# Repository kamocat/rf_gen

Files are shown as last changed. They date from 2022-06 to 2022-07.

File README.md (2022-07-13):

# RF Generator
500W RF generator, tuned for 13.56MHz
Based on the paper [1kW Wideband Class E Power Amplifier](https://superlab.stanford.edu/publication/kw_mhz_wideband_class_e_power_amplifier_jiale/) from the Stanford Superlab.

I removed the duplicate circuit (for simplicity), added a FET driver, clock, and Arduino for control.

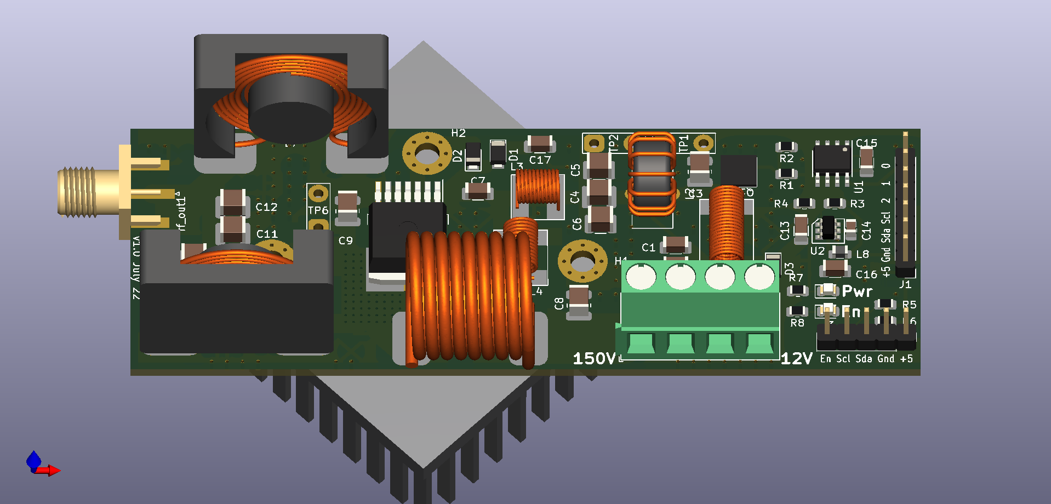
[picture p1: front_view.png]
Front view of PCBA Front View


## Cost breakdown
| Category | Price | Description |
| --- | --- | --- |
| Assemblies | 19.95 | Arduino & Si5351 |
| Components | 47.25 | Parts that get soldered on |
| Consumables | 33.94 | Solder and magnet wire |
| Hardware | 4.89 | Screws, heatsink, thermal interface pad |
| PCB | 30.00 | From OSH Park. 2 oz copper |

## Electrical simulation
Simulation is done with LTSpice.
You will need the spice models for the [SiC mosfet](https://www.genesicsemi.com/sic-mosfet/G3R30MT12J/G3R30MT12J_SPICE.zip) and the [GaN mosfet](https://gansystems.com/wp-content/uploads/2020/02/GS61004B-Spice-Models-V4P2.zip)

## Thermal simulation
Simulation is done with Elmer / FreeCAD. Work in progress...

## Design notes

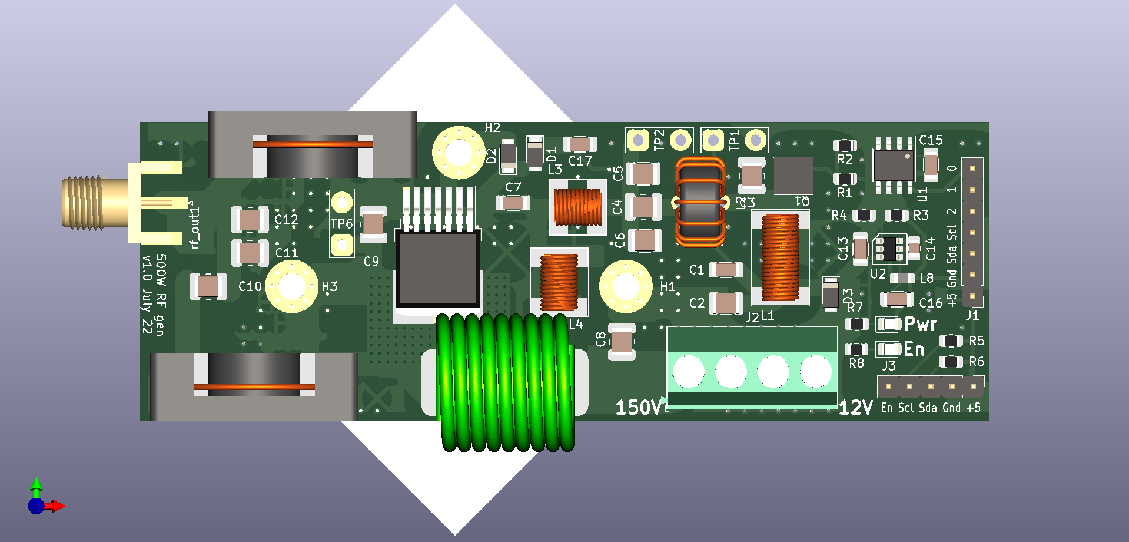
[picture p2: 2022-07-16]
top_view.png

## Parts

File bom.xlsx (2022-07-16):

Designator | Package | Quantity | Designation | Supplier and ref | Price | Extended | Category | Notes
R2,R1 | R_0805_2012Metric | 2 | 1 | 667-ERJ-6GEYJ1R0V | 0.054 | 0.108 | Component
R8,R7 | R_0805_2012Metric | 2 | 330 | 652-CR0805FX-3740ELF | 0.029 | 0.058 | Component
C14 | C_0805_2012Metric | 1 | 100n | 187-CL21B104KACNNNC | 0.028 | 0.028 | Component
C7,C1,C17 | C_1206_3216Metric | 3 | 100n | 81-GRM3195C1H104JA5D | 0.374 | 1.122 | Component
R6,R4,R5 | R_0805_2012Metric | 3 | 10k | 603-RT0805FRE0710KL | 0.08 | 0.24 | Component
C16,C13,C15 | C_1206_3216Metric | 3 | 10u | 187-CL31B106MOHNNNE | 0.09 | 0.27 | Component
L4 | 2222SQ-111 | 1 | 110n | 994-2222SQ-111JEC (https://www.mouser.com/ProductDetail/81-GRM3195C1H104JA5D) | 1.89 | 1.89 | Component
C9,C10 | C_1111_2828Metric | 2 | 180p | https://www.mouser.com/ProductDetail/Vishay-Vitramon/VJ1111D181KXGAJ?qs=FkXh%252BYPvS2puVPl%2FhgCUnw%3D%3D | 1.09 | 2.18 | Component
C6,C2 | C_1210_3225Metric | 2 | 1n | 581-12105U102JAT2A | 0.68 | 1.36 | Component
L1 | 2222SQ-221 | 1 | 220n | 994-2222SQ-221JEC (https://www.mouser.com/ProductDetail/621-DFLS230-7) | 1.85 | 1.85 | Component
C5,C3 | C_1111_2828Metric | 2 | 220p | 77-VJ1111D221JXLAJ (https://www.mouser.com/ProductDetail/710-150080GS75000) | 1.13 | 2.26 | Component
C8,C4,C11 | C_1111_2828Metric | 3 | 270p | 77-VJ1111D271JXLAJ (https://www.mouser.com/ProductDetail/485-2045) | 1.31 | 3.93 | Component
L8 | L_0805_2012Metric | 1 | 3.3u | 810-MLZ2012M3R3HT000 (https://www.mouser.com/ProductDetail/782-ABX00028) | 0.17 | 0.17 | Component
L7,L2 | 2929SQ-501 | 2 | 500n | https://www.mouser.com/ProductDetail/Coilcraft/2929SQ-501JEC?qs=zCSbvcPd3pbfVuBnETc4Rw%3D%3D | 2.07 | 4.14 | Component
R3 | R_0805_2012Metric | 1 | 52.3k | 603-RT0805FRE0752K3L (https://www.mouser.com/ProductDetail/994-2222SQ-90NJEC) | 0.081 | 0.081 | Component
L6 | inductor_air_15x15 | 1 | 760n | N/A | 0 | 0 | Component | Hand-wind, plastic 15mm core
L5 | inductor_air_15x15 | 1 | 880n | N/A | 0 | 0 | Component | Hand-wind, plastic 15mm core
L3 | 2222SQ-90N | 1 | 90n | 994-2222SQ-90NJEC | 1.85 | 1.85 | Component
U2 | TSOT26 | 1 | AP62150 | 621-AP62150WU-7 | 0.44 | 0.44 | Component
J3 | PinHeader_1x05_P2.54mm_Vertical | 1 | Conn_01x05_Male | 782-ABX00028 | 12 | 12 | Component
J1 | PinHeader_1x07_P2.54mm_Vertical | 1 | Conn_01x07_Male | 485-2045 (https://www.mouser.com/ProductDetail/905-G3R350MT12J) | 7.95 | 7.95 | Component
rf_out1 | SMA_EdgeMount | 1 | Conn_Coaxial | 712-CONSMA020.062-G (https://www.mouser.com/ProductDetail/667-ERJ-6GEYJ1R0V) | 3.93 | 3.93 | Component
D2,D3,D1 | D_PowerDI-123 | 3 | DFLS230 | 621-DFLS230-7 (https://www.mouser.com/ProductDetail/603-RT0805FRE0752K3L) | 0.7 | 2.1 | Component
Q2 | TO-263-7_heatsink | 1 | G3R350MT12J | 905-G3R350MT12J (https://www.mouser.com/ProductDetail/603-RT0805FRE0710KL) | 6.06 | 6.06 | Component
Q1 | GaNpx | 1 | GS61004B | 499-GS61004B-MR | 7.22 | 7.22 | Component
D4,D5 | LED_0805_2012Metric | 2 | LED | 710-150080GS75000 (https://www.mouser.com/ProductDetail/712-CONSMA020.062-G) | 0.019 | 0.038 | Component
H3,H1,H2 | MountingHole_3.2mm_M3_Pad_Via | 3 | MountingHole_Pad | 728-062809-008 | 0.05 | 0.15 | Hardware
U1 | SOIC-8_3.9x4.9mm_P1.27mm | 1 | NPC81074 | 863-NCP81074ADR2G | 1.63 | 1.63 | Component
J2 | TerminalBlock_Phoenix_MKDS-1,5-4-5.08_1x04_P5.08mm_Horizontal | 1 | Screw_Terminal_01x04 | 649-220316-H041B01LF | 0.89 | 0.89 | Component
TP6,TP1,TP2 | TestPoint_2Pads_Pitch5.08mm_Drill1.3mm | 3 | test | N/A | 0 | 0 | Component | For oscope probe
 | #16 Magnet Wire | 1 |  | Amazon (https://docs.oshpark.com/services/two-layer-hhdc/) | 11.45 | 11.45 | Consumable
 | Heat sink | 1 |  | HSB21-454515 (https://www.amazon.com/BNTECHGO-AWG-Magnet-Wire-Transformers/dp/B07H7GVR8L) | 2.11 | 2.11 | Hardware
 | PCB | 1 |  | OSH Park | 10 | 30 | PCB
 | Solder paste | 1 |  | 4902P-15G (https://www.mouser.com/ProductDetail/CUI-Devices/HSB21-454515?qs=QNEnbhJQKvZ3Ksj2ZU6gJQ%3D%3D) | 11.04 | 11.04 | Consumable
 | Thermal Interface Pad | 1 |  | 588-HS100-TP2 (https://www.mouser.com/ProductDetail/MG-Chemicals/4902P-15G?qs=YCa%2FAAYMW03JzXlgCTWNQA%3D%3D) | 2.63 | 2.63 | Hardware
 | Shipping |  |  |  |  | 7.99
 |  |  |  |  |  | 129.165

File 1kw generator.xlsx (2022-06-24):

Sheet: cost sheet
 |  |  |  |  |  |  |  |  | 14 awg = 1.6mm
Circuit | Component | PN | value | cost | qty | package | windings | length | wire diameter | resistance | power dissipated
Gate Drive
 | Sg | GS61004B (https://www.mouser.com/ProductDetail/GaN-Systems/GS61004B-MR?qs=OlC7AqGiEDkQI26Ffzps3A%3D%3D) | GAN fet | 7.22 | 1
 | Lf | 2222SQ-221_E_ (https://www.coilcraft.com/en-us/products/rf/air-core-inductors/square-air-core-inductors/1515sq-2222sq-2929sq/2222sq-221/) | 220 nH | 1.85 | 1
 | Cf |  | 220 pF | 0.06 | 1 | 0805
 | Ls | 5967000201 (https://www.mouser.com/ProductDetail/Fair-Rite/5967000201) | 650 nH | 0.85 | 1 |  | 6
 | Cs |  | 265 pF | 0.06 | 1 | 0805
 | Lm1 | 2222SQ-90N_E_ (https://www.coilcraft.com/en-us/products/rf/air-core-inductors/square-air-core-inductors/1515sq-2222sq-2929sq/2222sq-90n/) | 90 nH | 1.85 | 1
 | Cm |  | 1.5 nF | 0.01 | 1 | 0805
 | Lm2 | 2222SQ-111_E_ (https://www.coilcraft.com/en-us/products/rf/air-core-inductors/square-air-core-inductors/1515sq-2222sq-2929sq/2222sq-111/) | 110 nH | 1.85 | 1
 | Cb |  | 100 nF | 0.37 | 1 | 1206
 | D1, D2 | DFLS230 | schottky | 0.7 | 2
Power Amplifier
 | S1, S2 | G3R350MT12J (https://www.mouser.com/ProductDetail/GeneSiC-Semiconductor/G3R350MT12J?qs=zW32dvEIR3vCQ2poQ4Z4Lg%3D%3D) | SiC fet | 6.06 | 2
 | LF 1, LF 2 | 15mm air core | 880 nH |  | 2 |  | 9
 | CF 1, CF 2, CS1, CS2 | C0805C390JDGACTU (https://www.mouser.com/ProductDetail/KEMET/C0805C390JDGACTU?qs=NrXEK%2Fuukt6We1Uf8rN8WQ%3D%3D) | 39 pF | 0.26 | 4 | 1206
 | LS1, LS2 | 5967001001 (https://www.mouser.com/ProductDetail/Fair-Rite/5967001001) | 3.5 µH | 4.66 | 2 |  | 16
 | LP 1, LP 2 | 5967000301 (https://www.mouser.com/ProductDetail/Fair-Rite/5967000301) | 594 nH | 0.9 | 2 | 1206 | 6
 | CP 1, CP 2 |  | 232 pF | 0.29 | 2 | 1206
Controls
 | clock generator | Si5351 |  | 8.19
 | mcu | arduino |  | 15
 | display | OLED or 7seg |  | 2
 | knob | Encoder |  | 3

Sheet: inductor notes
Ref designator | Inductance | Resistance (mΩ) | Max current (A) | RMS current (A) | Heat loss (mW) | Core | Wire gauge | Length (mm) | Turns | OD (mm) | ID (mm) | height (mm)
L1 | 220nH | 11.0 | 2.5 | 1.6 | 17.6 | air
L2 | 650nH | 45.3 | 1.5 | 0.84 | 38.1 | mat 67 toroid | 20 | 123 | 6 | 9.5 | 4.75 | 3.3
L3 | 90nH | 5.5 | 4 | 1.75 | 9.6 | air
L4 | 110nH | 6.5 | 3.5 | 0.7 | 4.5 | air
L5 | 880nH | 49.7 | 10 | 7 | 348.1 | 15mm plastic tube | 20 | 135 | 9 | 15
L6 | 3.5uH | 99.5 | 5 | 3.5 | 348.1 | mat 67 toroid | 20 | 270 | 17.6 | 12.7 | 7.15 | 4.9
L7 | 584nH | 40.5 | 5 | 3.5 | 141.8 | mat 67 toroid | 20 | 110 | 7.2 | 12.7 | 7.15 | 4.9

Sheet: tools
K | 0.8
u0 | 1.256637061e-06 | Resources
uRod | 20 | Coil32 - Ferrite Rod Coil Calculator (https://coil32.net/online-calculators/ferrite-rod-calculator.html)
Turns | 6 | T50-2 (toroids.info)
Area (cm2) | 0.0707 | Rod Permeability Calculator - Fair Rite (fair-rite.com) (https://www.fair-rite.com/rods-calculator/)
pitch (mm) | 1.6 | https://learnemc.com/EXT/calculators/Resistance_Calculator/wire.html
length (cm) | 0.96
Inductance (uH) | 0.5330654415

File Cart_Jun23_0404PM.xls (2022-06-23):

SHOPPING CART
This is not an invoice
23-Jun-22 16:04:28
 | Mouser # | Mfr. # | Manufacturer | Customer # | Description | RoHS | Lifecycle | Order Qty. | Price (USD) | Ext.: (USD)
1 | 994-2222SQ-221JEC | 2222SQ-221JEC | Coilcraft |  | Fixed Inductors 2222 220nH Unshld 5% 5A 11mOhms | RoHS Compliant |  | 1 | $1.85 | $1.85
2 | 499-GS61004B-MR | GS61004B-MR | GaN Systems |  | MOSFET 100V, 38A, GaN E-mode, GaNPX package, Bottom-side cooled | RoHS Compliant |  | 1 | $7.22 | $7.22
3 | 994-2222SQ-90NJEC | 2222SQ-90NJEC | Coilcraft |  | Fixed Inductors 2222 90nH Unshld 5% 5A 5.5mOhms | RoHS Compliant |  | 2 | $1.85 | $3.70
4 | 905-G3R350MT12J | G3R350MT12J | GeneSiC Semiconductor |  | MOSFET 1200V 350mO TO-263-7 G3R SiC MOSFET | RoHS Compliant | New Product | 2 | $6.06 | $12.12
5 | 994-2222SQ-111JEC | 2222SQ-111JEC | Coilcraft |  | Fixed Inductors 2222 110nH Unshld 5% 5.7A 6.5mOhms | RoHS Compliant |  | 1 | $1.89 | $1.89
6 | 621-DFLS230-7 | DFLS230-7 | Diodes Incorporated |  | Schottky Diodes & Rectifiers 2.0A 30V LFF | RoHS Compliant By Exemption |  | 2 | $0.70 | $1.40
7 | 623-5967000301 | 5967000301 | Fair-Rite |  | Ferrite Toroids / Ferrite Rings 67 TOROID | RoHS Compliant |  | 2 | $0.90 | $1.80
8 | 623-5967000201 | 5967000201 | Fair-Rite |  | Ferrite Toroids / Ferrite Rings 67 TOROID 3.3mm 9.50mm | RoHS Compliant |  | 1 | $0.85 | $0.85
9 | 623-5967001001 | 5967001001 | Fair-Rite |  | Ferrite Toroids / Ferrite Rings 67 TOROID | RoHS Compliant |  | 2 | $4.66 | $9.32
10 | 81-GRM3195C1H104JA5D | GRM3195C1H104JA05D | Murata |  | Multilayer Ceramic Capacitors MLCC - SMD/SMT | RoHS Compliant |  | 10 | $0.374 | $3.74
11 | 77-VJ1111D390JXRAJ | VJ1111D390JXRAJ | Vishay |  | Multilayer Ceramic Capacitors MLCC - SMD/SMT 1111 39pF 1500V C0G 5% HI FREQ | RoHS Compliant By Exemption |  | 5 | $1.59 | $7.95
12 | 77-VJ1111D221JXLAJ | VJ1111D221JXLAJ | Vishay |  | Multilayer Ceramic Capacitors MLCC - SMD/SMT 1111 220pF 630V C0G 5% HI FREQ | RoHS Compliant By Exemption |  | 5 | $1.13 | $5.65
13 | 77-VJ1111D271JXLAJ | VJ1111D271JXLAJ | Vishay |  | Multilayer Ceramic Capacitors MLCC - SMD/SMT 1111 270pF 630V C0G 5% HI FREQ | RoHS Compliant By Exemption |  | 2 | $1.31 | $2.62
14 | 581-12105U471JAT2A | 12105U471JAT2A | Kyocera AVX |  | Multilayer Ceramic Capacitors MLCC - SMD/SMT 50V 470pF C0G 1210 5% Tol | RoHS Compliant |  | 2 | $0.77 | $1.54
15 | 581-12105U102JAT2A | 12105U102JAT2A | Kyocera AVX |  | Multilayer Ceramic Capacitors MLCC - SMD/SMT 50V 1000pF C0G 1210 5% | RoHS Compliant |  | 3 | $0.68 | $2.04
16 | 77-VJ1111D330JXLAJ | VJ1111D330JXLAJ | Vishay |  | Multilayer Ceramic Capacitors MLCC - SMD/SMT 1111 33pF 630V C0G 5% HI FREQ | RoHS Compliant By Exemption |  | 10 | $0.746 | $7.46
17 | 77-VJ1111D120GXGQJ | VJ1111D120GXGQJ | Vishay |  | Multilayer Ceramic Capacitors MLCC - SMD/SMT 1111 12pF 1000V C0G 2% HI FREQ | RoHS Compliant |  | 2 | $1.23 | $2.46
18 | 863-NCP81074ADR2G | NCP81074ADR2G | onsemi |  | Gate Drivers SINGLE CHANNEL 10A H | RoHS Compliant |  | 1 | $1.63 | $1.63
19 | 471-SMACONNECTOR | SMA CONNECTOR | LPRS |  | RF Connectors / Coaxial Connectors SMA Coaxial Straight | RoHS Compliant |  | 1 | $1.40 | $1.40
20 | 621-AP62150WU-7 | AP62150WU-7 | Diodes Incorporated |  | Switching Voltage Regulators DCDC Conv HV Buck TSOT26(STD) T&R 3K | RoHS Compliant | New Product | 1 | $0.44 | $0.44
21 | 187-CL31B106MOHNNNE | CL31B106MOHNNNE | Samsung Electro-Mechanics |  | Multilayer Ceramic Capacitors MLCC - SMD/SMT 10uF+/-20% 16V X7R 3 1206 | RoHS Compliant |  | 10 | $0.09 | $0.90
22 | 603-RT0805FRE0752K3L | RT0805FRE0752K3L | YAGEO |  | Thin Film Resistors - SMD 1/8W 52.3K ohm 1% 50ppm | RoHS Compliant By Exemption |  | 10 | $0.081 | $0.81
23 | 603-RT0805FRE0710KL | RT0805FRE0710KL | YAGEO |  | Thin Film Resistors - SMD 1/8W 10K ohm 1% 50ppm | RoHS Compliant By Exemption |  | 10 | $0.08 | $0.80
24 | 187-CL21B104KACNNNC | CL21B104KACNNNC | Samsung Electro-Mechanics |  | Multilayer Ceramic Capacitors MLCC - SMD/SMT 100nF+/-10% 25V X7R 0805 | RoHS Compliant |  | 10 | $0.031 | $0.31
25 | 485-2045 | 2045 | Adafruit |  | Clock & Timer Development Tools Adafruit Si5351A Clock Generator Breakout Board - 8KHz to 160MHz | RoHS Compliant |  | 1 | $7.95 | $7.95
26 | 782-ABX00028 | ABX00028 | Arduino |  | Development Boards & Kits - AVR ARDUINO NANO EVERY WO HEADERS | RoHS Compliant |  | 1 | $11.42 | $11.42
27 | 810-MLZ2012M3R3HT000 | MLZ2012M3R3HT000 | TDK |  | Fixed Inductors 3.3 UH 20% | RoHS Compliant |  | 2 | $0.17 | $0.34
By submitting your order you agree to these terms and conditions. (https://www.mouser.com/saleterms) |  |  |  |  |  |  |  |  | Merchandise: | $99.61
Prices are reflected at the date and time shown. |  |  |  |  |  |  |  |  | Shipping Charge: | $7.99

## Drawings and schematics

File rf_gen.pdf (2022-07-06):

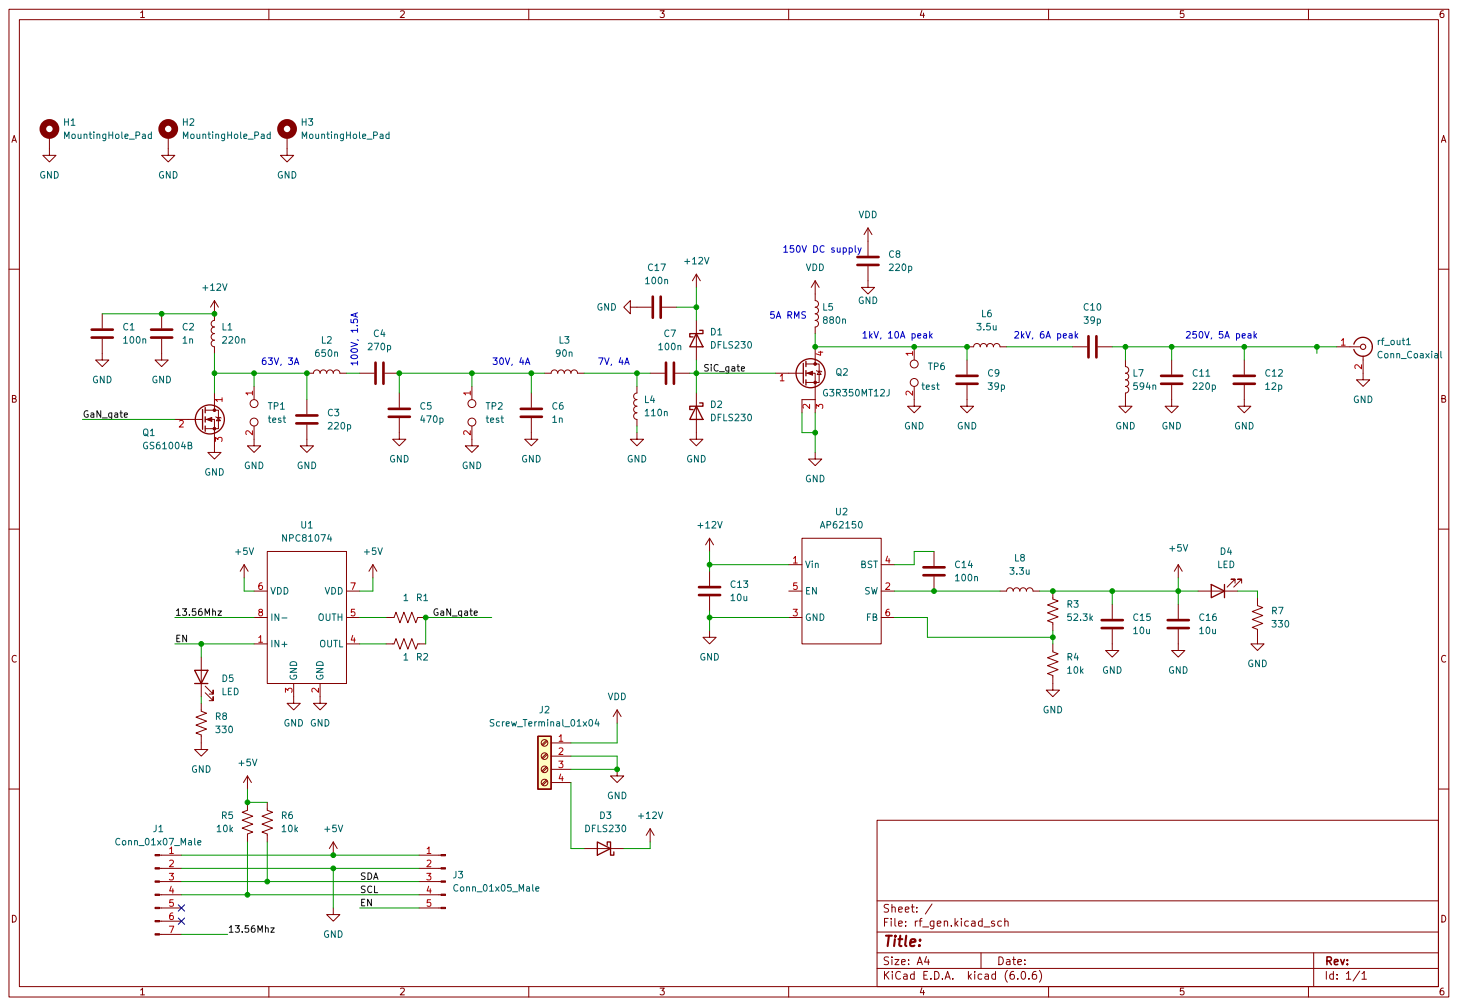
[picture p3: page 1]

3 OUTL 4 OUTH 5 VDD 6 VDD 7

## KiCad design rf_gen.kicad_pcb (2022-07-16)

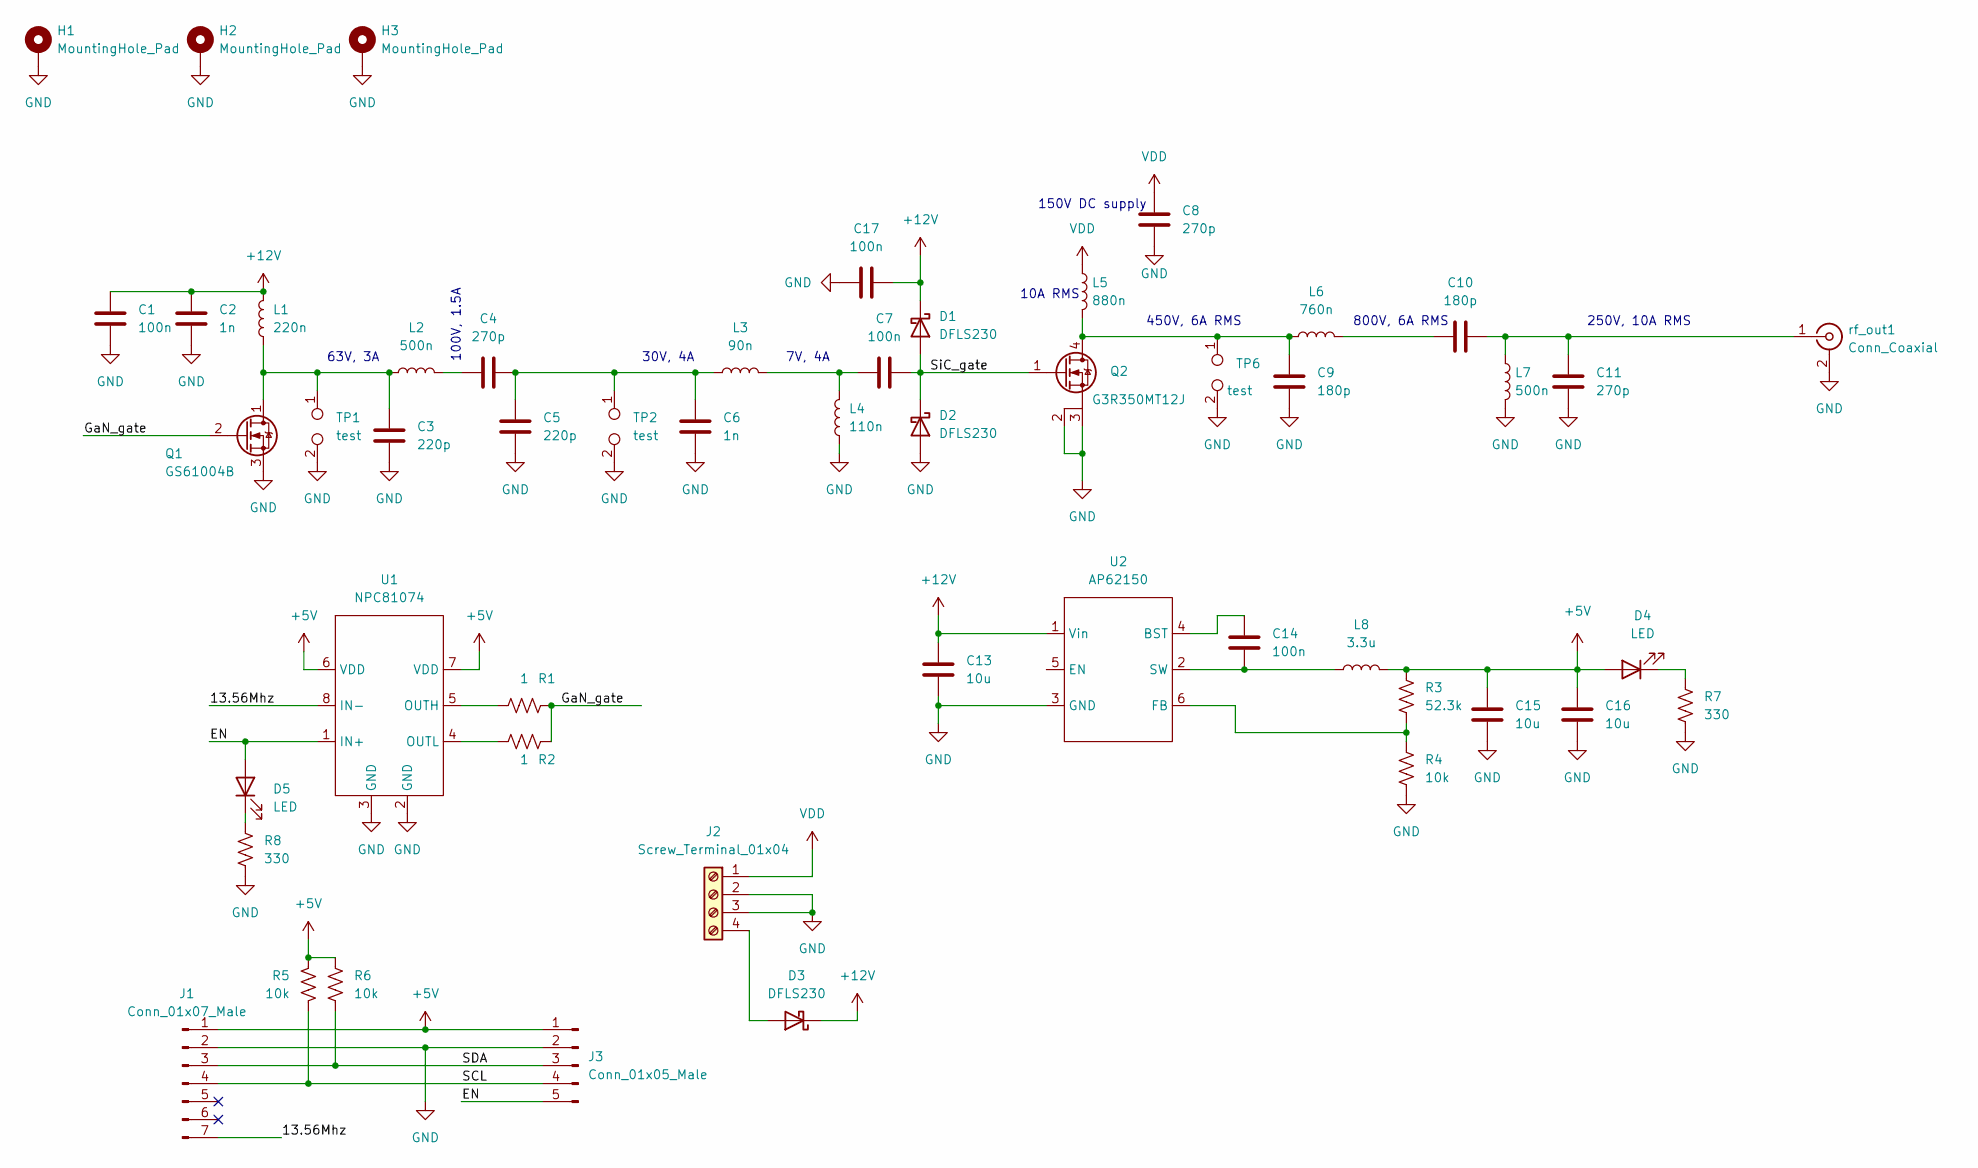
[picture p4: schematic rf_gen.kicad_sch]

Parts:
C1, C7, C17: 100n; C_1206_3216Metric
C2, C6: 1n; C_1210_3225Metric
C3, C5: 220p; C_1111_2828Metric
C4, C8, C11: 270p; C_1111_2828Metric
C9, C10: 180p; C_1111_2828Metric
C13, C15, C16: 10u; C_1206_3216Metric
C14: 100n; C_0805_2012Metric
D1, D2, D3: DFLS230; D_PowerDI-123
D4, D5: LED; LED_0805_2012Metric
H1, H2, H3: MountingHole_Pad; MountingHole_3.2mm_M3_Pad_Via
J1: Conn_01x07_Male; PinHeader_1x07_P2.54mm_Vertical
J2: Screw_Terminal_01x04; TerminalBlock_Phoenix_MKDS-1,5-4-5.08_1x04_P5.08mm_Horizont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
J3: Conn_01x05_Male; PinHeader_1x05_P2.54mm_Vertical
L1: 220n; 2222SQ-221
L2, L7: 500n; 2929SQ-501
L3: 90n; 2222SQ-90N
L4: 110n; 2222SQ-111
L5: 880n; inductor_air_15x15
L6: 760n; inductor_air_15x15
L8: 3.3u; L_0805_2012Metric
Q1: GS61004B; GaNpx
Q2: G3R350MT12J; TO-263-7_heatsink
R1, R2: 1; R_0805_2012Metric
R3: 52.3k; R_0805_2012Metric
R4, R5, R6: 10k; R_0805_2012Metric
R7, R8: 330; R_0805_2012Metric
TP1, TP2, TP6: test; TestPoint_2Pads_Pitch5.08mm_Drill1.3mm
U1: NPC81074; SOIC-8_3.9x4.9mm_P1.27mm
U2: AP62150; TSOT26
rf_out1: Conn_Coaxial; SMA_EdgeMount

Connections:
+5V: C15.1, C16.1, D4.2 (A), J1.1, J3.1, L8.2, R3.1, R5.2, R6.1, U1.6 (VDD), U1.7 (VDD)
+12V: C1.1, C2.2, C13.1, C17.2, D1.1 (K), D3.1 (K), L1.2, U2.1 (Vin)
/13.56Mhz: J1.7, U1.8 (IN-)
/EN: D5.2 (A), J3.5, U1.1 (IN+)
/GaN_gate: Q1.2 (G), R1.2, R2.2
/SCL: J1.4, J3.4, R5.1
/SDA: J1.3, J3.3, R6.2
/SiC_gate: C7.1, D1.2 (A), D2.1 (K), Q2.1 (G)
GND: C1.2, C2.1, C3.1, C5.2, C6.2, C8.1, C9.1, C11.2, C13.2, C15.2, C16.2, C17.1, D2.2 (A), H1.1, H2.1, H3.1, J1.2, J2.2, J2.3, J3.2, L4.1, L7.2, Q1.3 (S), Q2.2 (KS), Q2.3 (S), R4.2, R7.2, R8.2, TP1.2, TP2.2, TP6.2, U1.2 (GND), U1.3 (GND), U2.3 (GND), rf_out1.2 (Ext)
unnamed: C3.2, L1.1, L2.1, Q1.1 (D), TP1.1
unnamed: C4.1, L2.2
unnamed: C4.2, C5.1, C6.1, L3.1, TP2.1
unnamed: C7.2, L3.2, L4.2
unnamed: C9.2, L5.2, L6.1, Q2.4 (D), TP6.1
unnamed: C10.1, L6.2
unnamed: C10.2, C11.1, L7.1, rf_out1.1 (In)
unnamed: C14.1, U2.4 (BST)
unnamed: C14.2, L8.1, U2.2 (SW)
unnamed: D3.2 (A), J2.4
unnamed: D4.1 (K), R7.1
unnamed: D5.1 (K), R8.1
unnamed: R1.1, U1.5 (OUTH)
unnamed: R2.1, U1.4 (OUTL)
unnamed: R3.2, R4.1, U2.6 (FB)
VDD: C8.2, J2.1, L5.1

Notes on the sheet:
100V, 1.5A
63V, 3A
250V, 10A RMS
10A RMS
800V, 6A RMS
7V, 4A
450V, 6A RMS
30V, 4A
150V DC supply

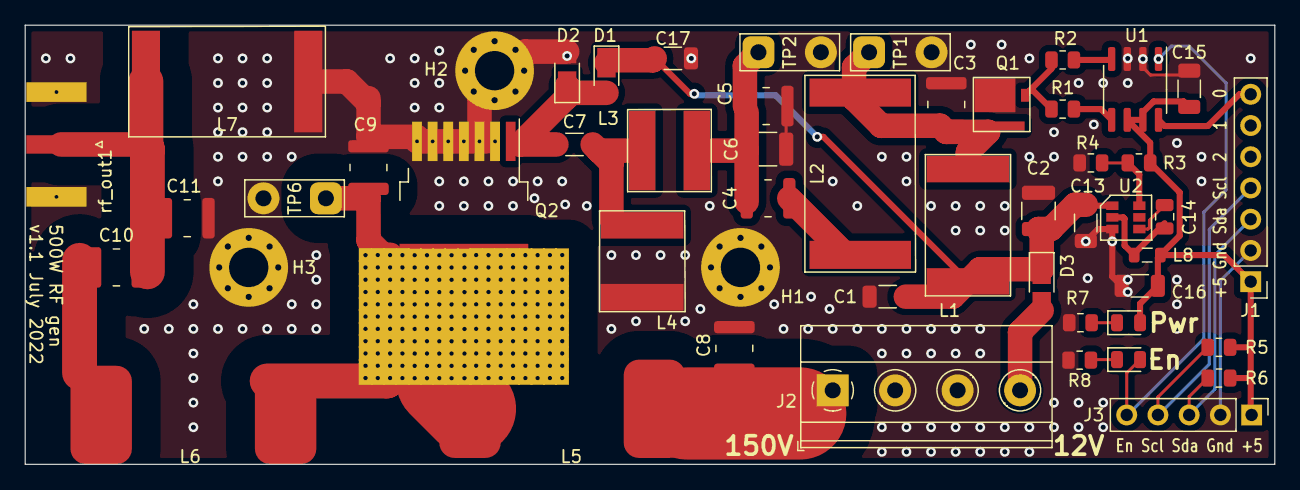
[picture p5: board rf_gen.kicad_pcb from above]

Board: 2 copper layers, 101.6 x 35.7 mm, 51 parts (0 on the bottom side), 25 nets.

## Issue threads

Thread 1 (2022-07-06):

Heat sink

kamocat, 2022-07-06:
Although this generator should be extremely efficient, it needs some way of dissipating heat. 90% efficient at 500W still means 50W output as heat.
The reference design appears to use screws to hold the PCB to a heat sink. This could work, although I'm worried about clearance/creepage due to the high voltage. It also requires me to switch to surface-mount components, at least for the power inductors near the SiC fet.

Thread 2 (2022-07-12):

Safety Isolation

kamocat, 2022-07-12:
It would be nice to have the low-voltage controls electrically isolated from the high-voltage amplifier.

- Magnetic Isolation (Replace L2 with a transformer).
- Capacitive isolation. Lots of options, maybe C7? Creates current path between grounds
- Optical isolation. Too slow for the RF, but could work for RS232 or RS485. Or the i2c. Requires yet another power supply.

The first two options create a problem for the upper clamping diode (D1). Shunting this through a zener or similar could hurt the efficiency of the driver. But moving the clamping diodes further away from the gate introduce the possibility of exceeding the gate voltage.

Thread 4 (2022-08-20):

Disable causes short

kamocat, 2022-08-20:
Pulling the EN pin low will stop the RF, but will leave the SiC transistor turned on.
This will burn up the transistor, the PCB traces, and possibly an inductor.
Need a way of turning off both transistors. Possibly a MOSFET to clamp the SiC gate to 0V?

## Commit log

2022-06-23 First draft of schematic
    [rf_gen.kicad_pcb, rf_gen.kicad_sch]
2022-06-23 Added Mouser BOM
    [Cart_Jun23_0404PM.xls, rf_gen.kicad_sch]
2022-06-24 Added CoilCraft footprints
    Using approximate footprints for the toroids for now
    [rf_gen.kicad_pcb, rf_gen.kicad_sch]
2022-06-24 First draft of PCB layout
    [rf_gen.kicad_pcb, rf_gen.kicad_sch]
2022-06-24 Added simulation and design notes
    [1kw generator.xlsx, rf_gen.kicad_pcb, rf_gen.kicad_sch]
2022-07-05 Added netclasses, test points, fixed buck regulator
    [rf_gen.kicad_pcb, rf_gen.kicad_sch]
2022-07-05 Draft of trace routing
    [rf_gen.kicad_pcb, rf_gen.kicad_sch]
2022-07-05 Finished routing
    Replaced power inductor footprints with actual sizes
    Placed test points that seemed useful, removed ones that didn't fit
    Replaced RF connector and power input connectors
    Added LED to indicate power
    Added stitching vias
    [rf_gen.kicad_pcb, rf_gen.kicad_sch]
2022-07-06 Added KiCAD BOM
    [bom.xlsx]
2022-07-06 Added heatsink
    Switched power inductors to surface-mount to avoid shorting
    Added silkscreen text for connectors and LEDs
    [bom.xlsx, rf_gen.kicad_pcb, rf_gen.kicad_sch]
2022-07-06 Finishing touches
    Fixed design violations. Had to make exceptions for 1kV due to the dimensions of the parts
    Added top and front views of PCB
    [rf_gen.kicad_pcb, rf_gen.kicad_sch]
2022-07-08 Added 3D models for footprints
    [bom.xlsx, rf_gen.kicad_pcb]
2022-07-08 Added heatsink, improved eq core windings
    [rf_gen.kicad_pcb]
2022-07-16 Added 3d model for toroid inductor
    [rf_gen.kicad_pcb, rf_gen.kicad_sch]
2022-07-16 Fixed DRC issues
    Buck regulator was wired incorrectly. Not sure how this happened.
    Increased spacing between pads on RF capacitor to reduce chance of arcing
    [rf_gen.kicad_pcb]
2022-07-16 Removed thermal reliefs on GND plane
    [rf_gen.kicad_pcb]
2022-07-16 Fixed board stackup dimensions
    [rf_gen.kicad_pcb]
2022-07-16 Added GaN FET model to SPICE sim
2022-07-16 Changed output filter to handle lower impedance
    [rf_gen.kicad_sch]
2022-07-16 Changed L2 to use CoilCraft inductor
    [rf_gen.kicad_sch]
2022-07-16 Updated PCB due to inductor changes
    [rf_gen.kicad_pcb, rf_gen.kicad_sch]
2022-07-16 Updated BOM to reflect cost reductions
    Removed ferrite cores from inductors
    Changed L2 and L7 to standard parts
    Consolidated some capacitor values
    [bom.xlsx]
